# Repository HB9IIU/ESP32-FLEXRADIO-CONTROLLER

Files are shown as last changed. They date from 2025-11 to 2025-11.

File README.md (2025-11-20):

# FlexControl WiFi – ESP32 SmartSDR Tuning Knob

**FlexControl WiFi** is an ESP32-based network controller for **FlexRadio SmartSDR**.  
It talks to the SmartSDR CAT server over TCP (port 5002) and gives you a **hardware tuning knob** with:

- Main VFO encoder (with acceleration)
- Filter preset encoder (0–7)
- Volume encoder with mute
- Touch buttons for frequency presets, PTT and TUNE
- Mode cycling (USB / LSB )
- Status LEDs for CAT link and TX
- Captive-portal Wi-Fi configuration + OTA firmware updates

👉 All code and 3D enclosure files are **free and open source**.

## Demo Video

<p align="center">
  <a href="https://www.youtube.com/watch?v=9js4Cu4pR5Q" target="_blank">
    FlexControl WiFi Demo
  </a>
</p>

## Features

- 🌀 **Main tuning encoder**  
  - High-resolution quadrature decoder in ISR  
  - Frequency acceleration based on tuning speed  
  - Periodic `FA;` polling to keep in sync with SmartSDR

- 🎚 **Filter encoder**  
  - 8 filter presets: CAT command `ZZFI00`…`ZZFI07`  
  - Encoder steps mapped to filter index 0–7

- 🔊 **Volume encoder + mute**  
  - Volume 0–100% via `ZZAGnnn;`  
  - Mute / unmute on volume encoder click (remembers last volume)  
  - Auto-unmute if you turn the volume knob while muted

- 🧲 **Touch buttons (TTP223 modules)**  
  - Touch 1: FT8 @ **40 m** preset (7.077 MHz, LSB)  
  - Touch 2: FT8 @ **20 m** preset (14.074 MHz, USB)  
  - Touch 3: **PTT** (press & hold = TX, release = RX)  
  - Touch 4: **TUNE** (short carrier, low power, configurable)  
  - Touch 5: **Mode cycle** (USB ↔ LSB, extendable)

- 🧠 **Smart CAT handling**  
  - Auto-discovery of the SmartSDR CAT server on LAN  
  - Caching of last known CAT host in NVS (`Preferences`)  
  - Transparent handling of modes (MDn;), power (ZZPC), PTT (ZZTX)

- 🌐 **Wi-Fi captive portal + OTA**  
  - First-boot captive portal to capture Wi-Fi credentials  
  - Web console logger (serial-over-web)  
  - OTA updates via ArduinoOTA helper

- 🔁 **Factory reset**  
  - Press and hold factory reset button at boot to clear Wi-Fi / NVS  
  - Red LED indicates reset activity

---

## Hardware

- **ESP32 board** (classic ESP32 DevKit-style with GPIOs 32/33 etc.)
- Main VFO: high-resolution E38 optical encoder (600 PPR, NPN, powered at 5 V, A/B pulled up to 3.3 V on the ESP32).
- Filter & volume: two HW-040 mechanical encoders with integrated push switches (volume switch also used for mute / factory reset).
- 5× **TTP223 touch sensors** 
- 2× LEDs (GREEN, RED) for status and TX indication
- 1× **factory-reset / volume encoder** push button
- 3D-printed enclosure (STL/STEP files in this repo)

> 🛠 All 3D files for the enclosure are included in the repository.  
> Check the `doc/` folder for STEP/STL files.

---

## Wiring

Below is the wiring as used in the firmware (`main.cpp`).

### LEDs

| Function | ESP32 GPIO | Notes |
| --- | --- | ---|
| GREEN status LED  | **13** | CAT connected / mute indication |
| RED status / TX | **4** | TX, errors, blinking, reset LED |

> Both the “red LED” and the “reset LED” share GPIO 4 in the code.

### Rotary Encoders

All encoder A/B signals are read with internal pull-ups (`INPUT_PULLUP`).  
Encoder common pins go to **GND**.

#### Main VFO Encoder (frequency)

| Signal | ESP32 GPIO | Notes |
| --- | --- | --- |
| Encoder A  | **32** | Quadrature A |
| Encoder B  | **33** | Quadrature B |
| Push (BW)  | **16** | Active-LOW, internal pull-up |

#### Filter / BW Encoder

| Signal | ESP32 GPIO | Notes |
| --- | --- | ---|
| Encoder A | **26** | Quadrature A |
| Encoder B | **25** | Quadrature B |
| Push (BW) | **16** | Active-LOW, used to reboot the ESP32 (BW button) |

#### Volume Encoder

| Signal | ESP32 GPIO | Notes |
| --- | --- | --- |
| Encoder A  | **14** | Quadrature A |
| Encoder B  | **27** | Quadrature B |
| Push | **17** | Active-LOW, internal pull-up (also used for **factory reset** at boot) |

> Long-press on boot = factory reset (via `HB9IIUPortal::checkFactoryReset()`),  
> short press in normal operation = **mute / unmute**.

### Touch Buttons (TTP223)

TTP223 modules are wired as:

- `OUT` → corresponding GPIO (below)  
- `VCC` → 3.3 V  
- `GND` → GND

The firmware uses `INPUT_PULLDOWN`, with **touch = HIGH**, **idle = LOW**.

| Touch # | ESP32 GPIO | Function in firmware |
| --- | --- | --- |
| 1 | **23** | FT8 40 m preset (7.077 MHz, LSB) |
| 2 | **22** | FT8 20 m preset (14.074 MHz, USB)  |
| 3 | **21** | PTT (press = TX, release = RX) |
| 4 | **19** | TUNE (short carrier, low power) |
| 5 | **18** | Mode cycle (USB ↔ LSB) |

### Factory Reset

| Signal | ESP32 GPIO | Notes |
| --- | --- | --- |
| Factory reset button | **17** | Same physical button as volume push |
| Factory reset LED | **4** | Same red LED as TX / status |

At boot, `HB9IIUPortal::checkFactoryReset()` inspects this button to decide whether to erase NVS / Wi-Fi credentials.

---

## Firmware Overview

### Wi-Fi & Captive Portal

The project uses a custom helper:

- `HB9IIUPortal::begin()`  
  - Connects to stored Wi-Fi credentials if available  
  - Otherwise starts an **Access Point + captive portal** (`HB9IIUportalConfigurator.h`)  
  - Shows a status message in the web console

---
### 3D Renderings

<table>
  <tr>
    <td></td>
    <td></td>
    <td></td>
    <td></td>
  </tr>
  <tr>
    <td></td>
    <td></td>
    <td></td>
    <td></td>
  </tr>
</table>

---

### As-Built

<table>
  <tr>
    <td></td>
    <td></td>
    <td></td>
    <td></td>
  </tr>   

</table>

---
## Known Limitations & Notes

- **SmartSDR reconnect behaviour**  
  If you **power off the device while SmartSDR is running**, the controller can reconnect, but SmartSDR sometimes stops reacting to it until you **restart SmartSDR**.  
  If you instead do a **soft restart** of the controller by clicking the **BW (filter) encoder** (which reboots the ESP32), SmartSDR continues to work normally without needing a restart.

- **Touch sensor sensitivity**  
  The TTP223 touch sensors are very sensitive through the front panel. With the current enclosure wall thickness, they can sometimes trigger even when a finger is **2–3 mm away** from the plastic.  
  If I were to redesign the enclosure, I would **increase the thickness** in the touch sensor area (or reduce sensitivity) to make accidental triggers less likely.

## Final Notes

This is a hobby project built by an amateur coder and radio tinkerer – expect a few quirks and feel free to hack it to your needs.  
Have fun experimenting, modifying and improving the controller… and if you build your own version, I’d be happy to see it!

73 de HB9IIU

## License

This project is licensed under the **GNU General Public License v3.0 (GPL-3.0)**.

You are free to use, modify, and redistribute this software, including in commercial products, as long as any distributed derivative works are also licensed under GPL-3.0 and accompanied by their complete corresponding source code.

See the [LICENSE](./LICENSE) file for the full text.

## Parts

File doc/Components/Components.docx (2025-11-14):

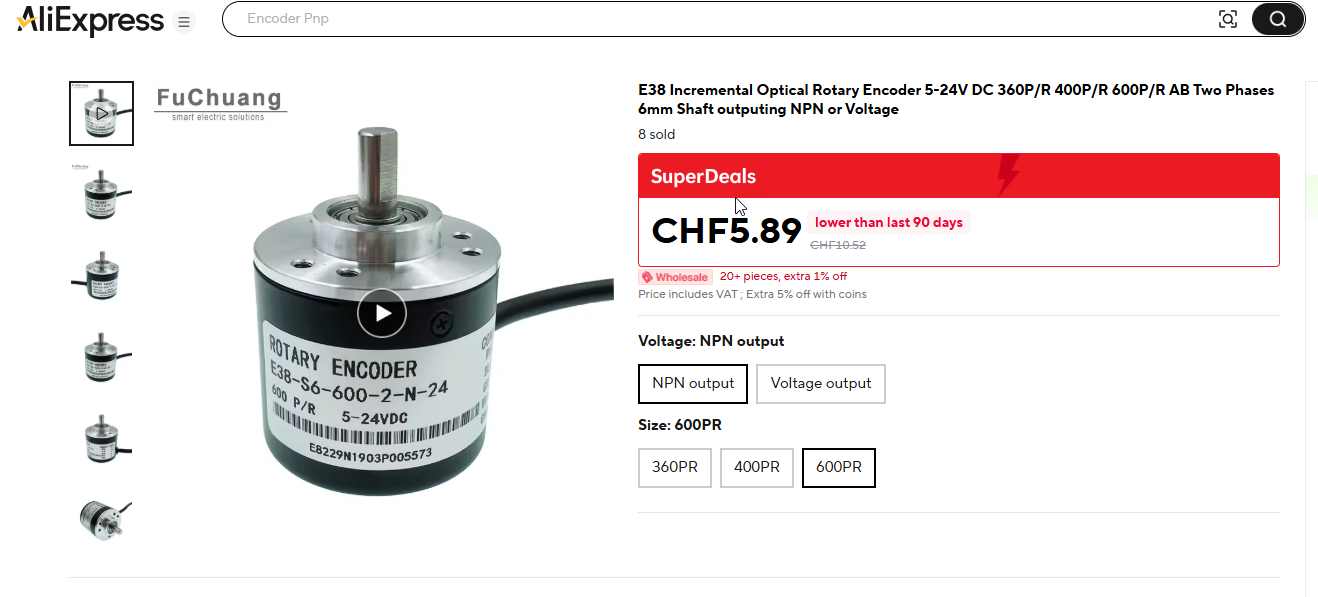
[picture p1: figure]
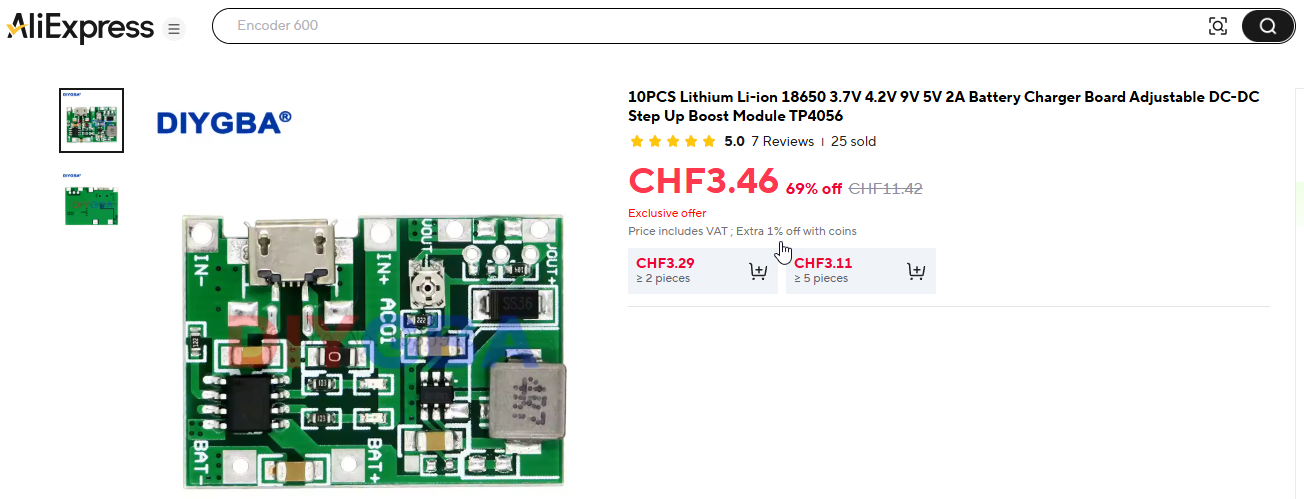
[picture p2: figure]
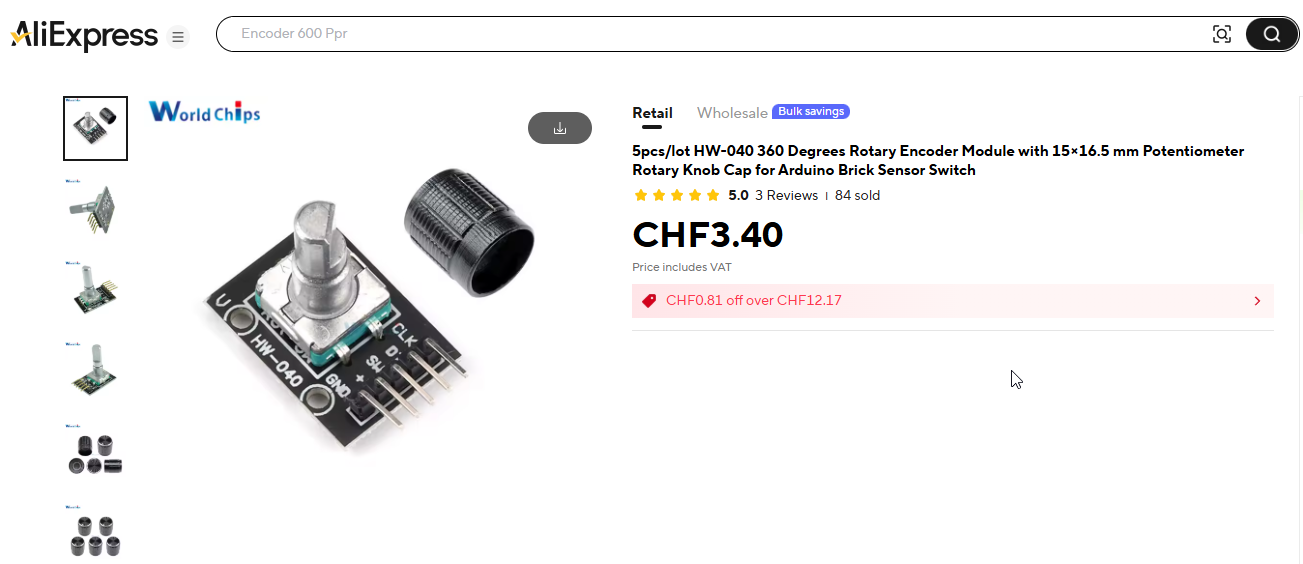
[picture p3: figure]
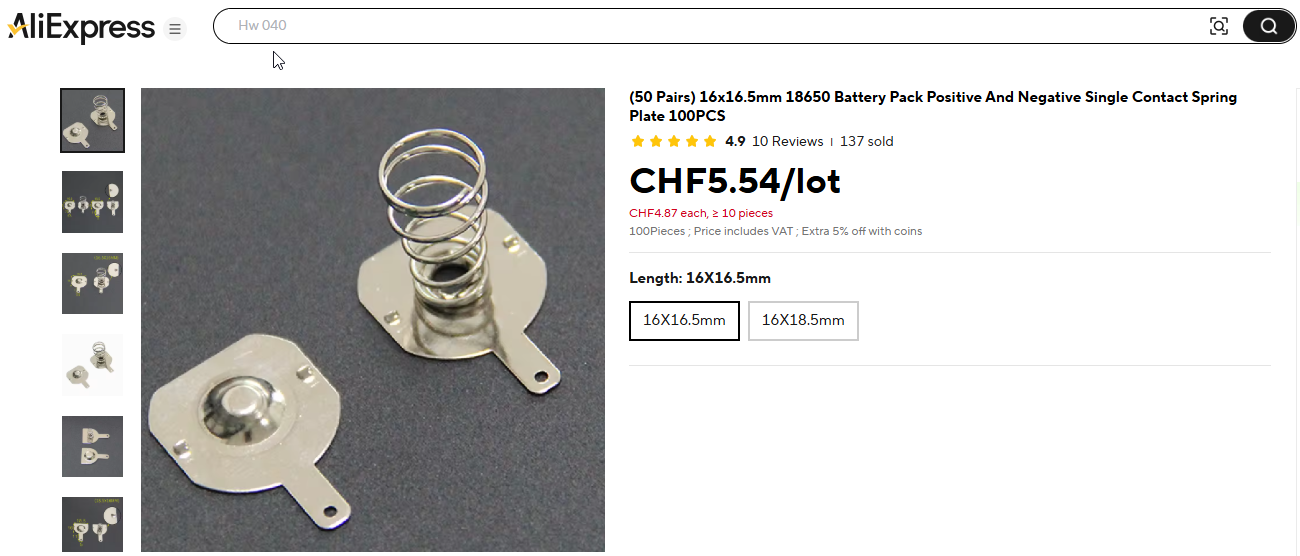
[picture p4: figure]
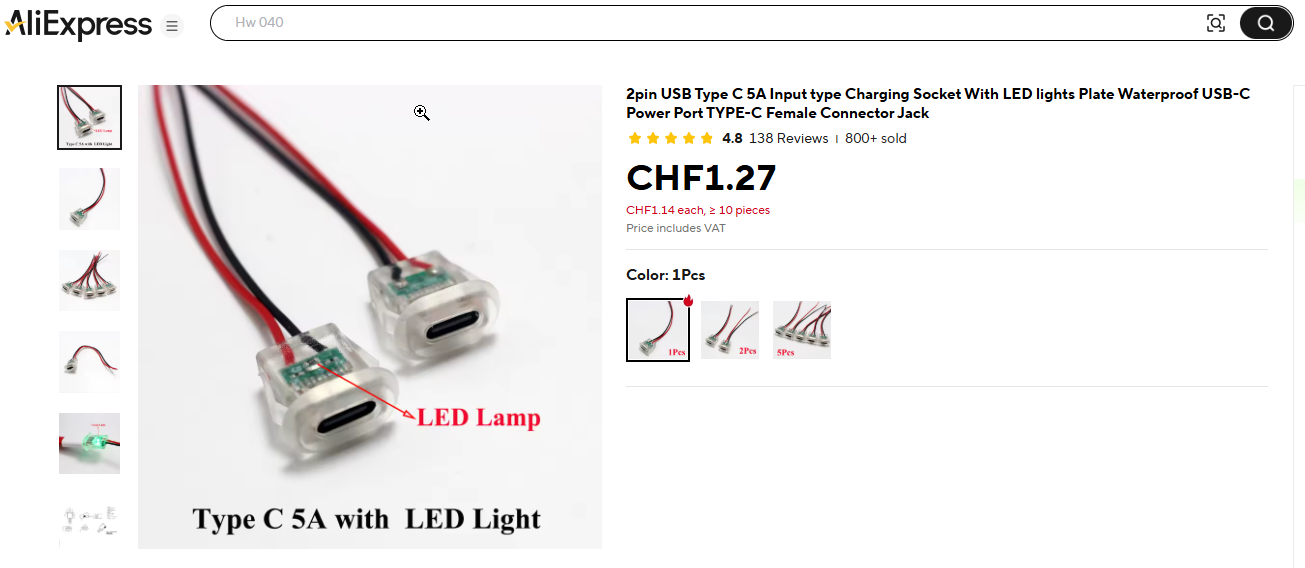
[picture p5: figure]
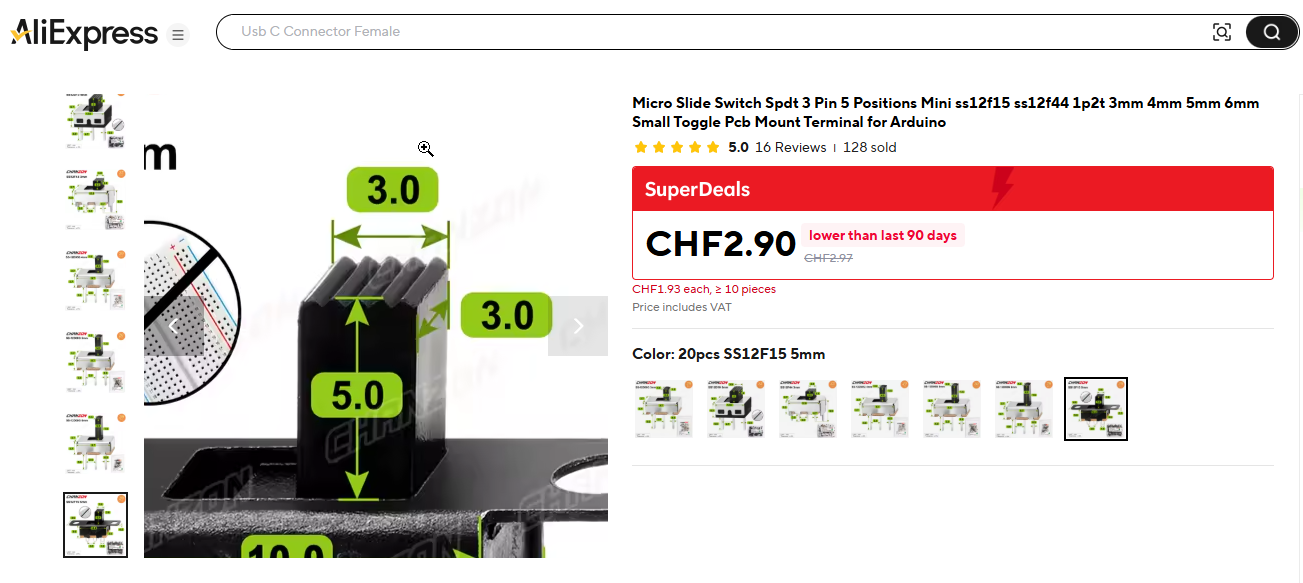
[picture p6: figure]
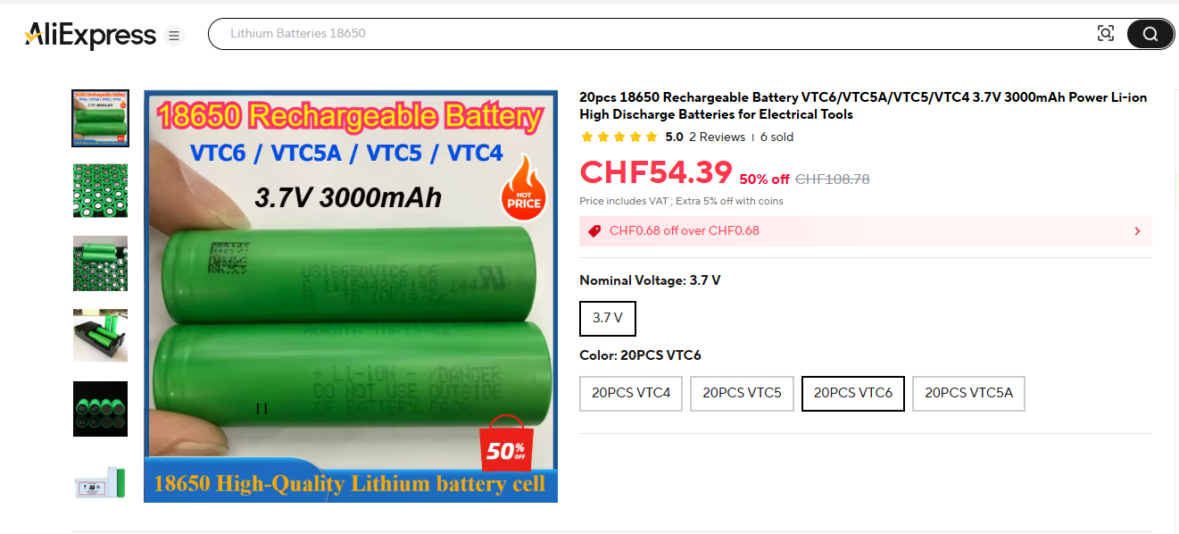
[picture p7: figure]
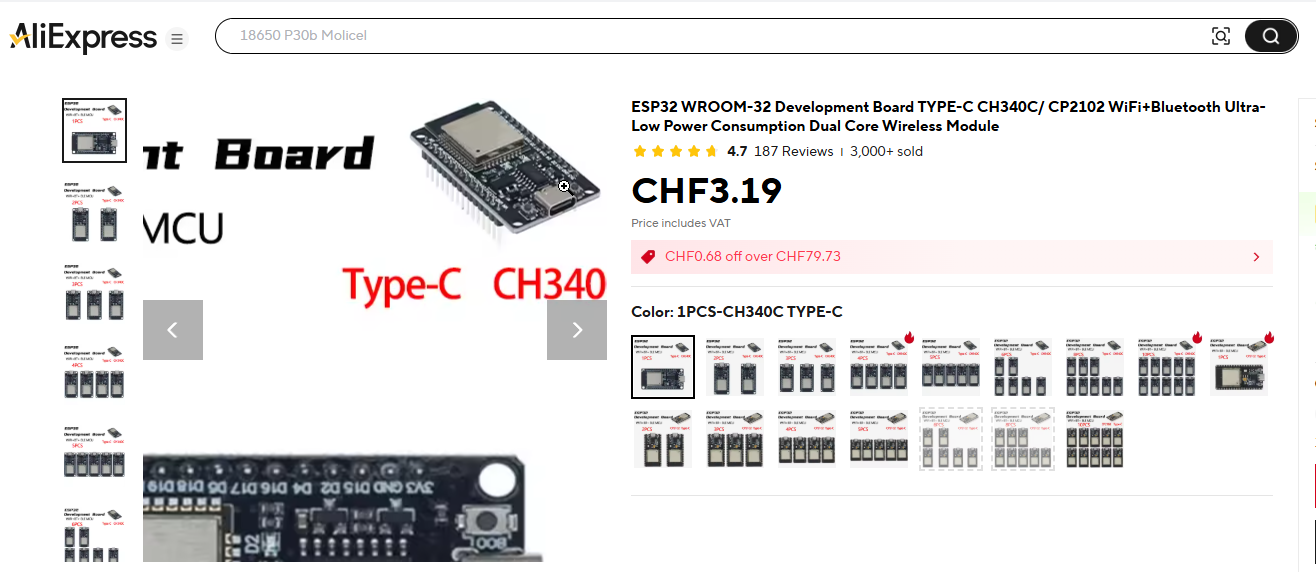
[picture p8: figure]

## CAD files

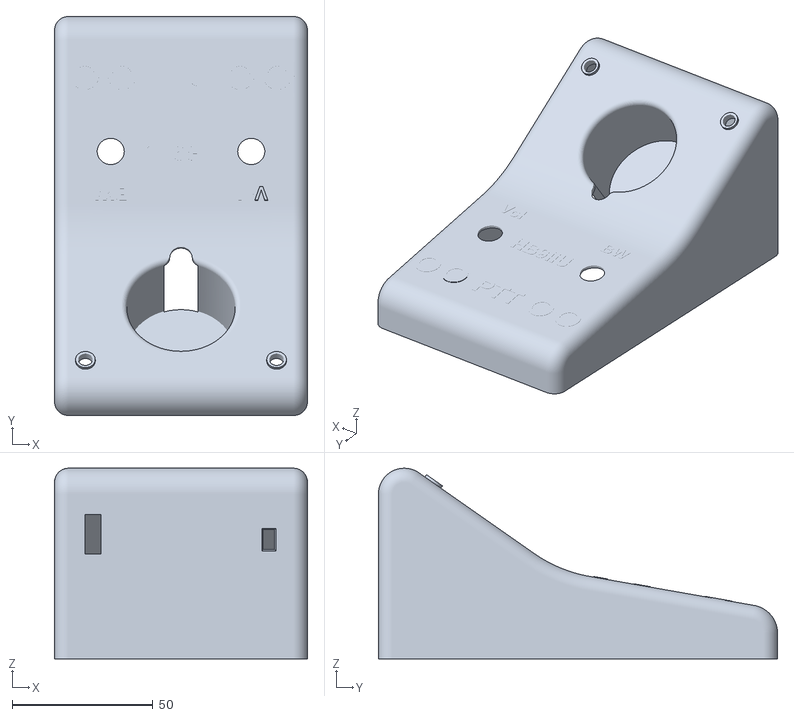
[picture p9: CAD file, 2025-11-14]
doc/STL files/TOP.stl
90.0 x 142.0 x 67.8

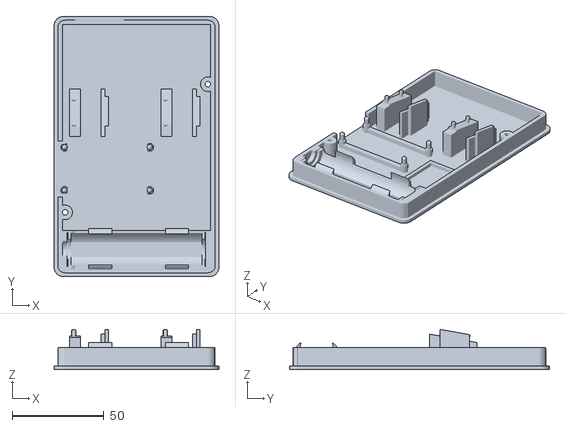
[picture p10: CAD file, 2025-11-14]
doc/STL files/BOTTOM.stl
90.0 x 142.0 x 21.9

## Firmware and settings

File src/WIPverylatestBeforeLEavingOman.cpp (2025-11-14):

/*
  ESP32 -> SmartSDR CAT (Kenwood FA) + Encoders + Preferences + Auto-Discover
  + 5x TTP223 Touch Inputs (active-HIGH, idle LOW) with simple debounce
  + 2x Encoder Click Buttons (active-LOW with INPUT_PULLUP) with simple debounce
/*
  TTP223 wiring:
  - VCC = 3.3V, GND = GND, OUT -> GPIO (18/19/21/22/23 here)
  - Pins are set to INPUT_PULLDOWN (idle LOW). Touch drives them HIGH.

  Encoder click buttons:
  - One side to GPIO (16 / 17), the other side to GND.
  - Pins use INPUT_PULLUP, so pressed = LOW.



  Touch1 = FT8 40m (7.074 MHz)
  Touch2 = FT8 20m (14.074 MHz)
  Freq Encoder Click = FT8 40m
  Vol  Encoder Click = FT8 20m
  Serial: 115200



*/

#include <WiFi.h>
#include <Preferences.h>

// ===== YOUR SETTINGS =====
const char *WIFI_SSID = "NO WIFI FOR YOU!!!";
const char *WIFI_PASS = "Nestle2010Nestle";
const IPAddress CAT_HOST(192, 168, 0, 5); // fallback if no cache / cache fails
const uint16_t CAT_PORT = 5002;
// =========================

// --- discovery timeouts (fast) ---
const uint32_t TCP_CONNECT_TIMEOUT_MS = 150;
const uint32_t SCAN_START_DELAY_MS = 800;
const uint8_t SCAN_BREATHER_MS = 6;

// --- LEDS ---
const int PIN_LED_GREEN = 13;
const int PIN_LED_RED = 4;

// ---- MAIN ENCODER (frequency) ----
const int PIN_ENC_A = 32;
const int PIN_ENC_B = 33;

// ---- FILTER ENCODER (preset 0..7) ----
const int PIN_FILT_A = 26;
const int PIN_FILT_B = 25;

// ---- VOLUME ENCODER ----
const int PIN_VOL_A = 14;
const int PIN_VOL_B = 27;

// ---- ENCODER CLICK BUTTONS (active-LOW with internal pull-ups) ----
const int PIN_ENC_BW_SW = 16;  // click of main (frequency) encoder
const int PIN_ENC_VOL_SW = 17; // click of volume encoder

// ---- VOLUME STEP (percent per detent) ----
const int VOLUME_STEP = 5; // change to 2/5/10 as you like

#define ENC_INPUT_MODE INPUT_PULLUP

// Frequency step/behavior
const int32_t STEP_HZ = 1;
const uint32_t SEND_INTERVAL_MS = 60;
const uint32_t RESYNC_MS = 800;
const uint32_t ACCEL_T1_MS = 35;
const uint32_t ACCEL_T2_MS = 80;

// ---- FT8 frequencies (Hz) ----
const uint32_t FT8_40M_HZ = 7077000UL;  // 7.074 MHz normally but i wat to hear LSB (just to see if teher is activity)
const uint32_t FT8_20M_HZ = 14074000UL; // 14.074 MHz

// ---- TTP223 TOUCH PINS (active-HIGH, idle LOW) ----
const int PIN_TOUCH1 = 23;
const int PIN_TOUCH2 = 22;
const int PIN_TOUCH3 = 21;
const int PIN_TOUCH4 = 19;
const int PIN_TOUCH5 = 18;

// Simple debounce
const uint16_t TOUCH_DEBOUNCE_MS = 50;
bool touchLast1 = false, touchLast2 = false, touchLast3 = false, touchLast4 = false, touchLast5 = false;
uint32_t touchT1 = 0, touchT2 = 0, touchT3 = 0, touchT4 = 0, touchT5 = 0;

// Encoder click debounce (active-LOW)
const uint16_t CLICK_DEBOUNCE_MS = 50;
bool clickLastBW = false, clickLastVol = false; // "pressed" state (LOW) after inversion
uint32_t clickTBW = 0, clickTVol = 0;

WiFiClient cat;
Preferences prefs;
IPAddress currentHost = CAT_HOST;

uint32_t vfoHz = 14110000, lastSentHz = vfoHz;

// ---------- Quadrature decoder (ISR) : MAIN ----------
static const int8_t QDEC_TAB[16] = {
    0, -1, +1, 0, +1, 0, 0, -1, -1, 0, 0, +1, 0, +1, -1, 0};

volatile uint8_t q_last = 0;
volatile int32_t q_edges = 0;
volatile uint32_t lastDetentMs = 0;
volatile int32_t detentPending = 0;
volatile bool needResetEncoderBaseline = false;

inline uint8_t fastReadAB()
{
  return (uint8_t(digitalRead(PIN_ENC_A)) << 1) | uint8_t(digitalRead(PIN_ENC_B));
}

void IRAM_ATTR encISR()
{
  uint8_t now = fastReadAB();
  uint8_t idx = (q_last << 2) | now;
  int8_t d = QDEC_TAB[idx];
  if (d)
  {
    q_edges += d;
    detentPending += d;
    if (detentPending >= 4 || detentPending <= -4)
    {
      lastDetentMs = millis();
      detentPending = 0;
    }
  }
  q_last = now;
}

// ---------- FILTER ENCODER ----------
volatile uint8_t f_q_last = 0;
volatile int32_t f_edges = 0;
int8_t filterIdx = 0; // 0..7

inline uint8_t fastReadAB_filt()
{
  return (uint8_t(digitalRead(PIN_FILT_A)) << 1) | uint8_t(digitalRead(PIN_FILT_B));
}

void IRAM_ATTR filtISR()
{
  uint8_t now = fastReadAB_filt();
  uint8_t idx = (f_q_last << 2) | now;
  int8_t d = QDEC_TAB[idx];
  if (d)
    f_edges += d;
  f_q_last = now;
}
// ---- LED helpers ----
inline void ledsOff()
{
  digitalWrite(PIN_LED_GREEN, LOW);
  digitalWrite(PIN_LED_RED, LOW);
}
inline void ledGreenSolid()
{
  digitalWrite(PIN_LED_GREEN, HIGH);
  digitalWrite(PIN_LED_RED, LOW);
}
inline void ledRedSolid()
{
  digitalWrite(PIN_LED_GREEN, LOW);
  digitalWrite(PIN_LED_RED, HIGH);
}

// Blink RED/GREEN alternately for durationMs (used instead of blocking delays)
void blinkAlt(uint32_t durationMs, uint16_t periodMs = 150)
{
  uint32_t t0 = millis();
  bool phase = false;
  while (millis() - t0 < durationMs)
  {
    // phase=false -> RED on, GREEN off; phase=true -> GREEN on, RED off
    digitalWrite(PIN_LED_RED, phase ? LOW : HIGH);
    digitalWrite(PIN_LED_GREEN, phase ? HIGH : LOW);
    phase = !phase;
    delay(periodMs); // replaces the old blocking delay(...)
  }
  ledsOff(); // stop blinking after the timed window
}

// --- non-blocking GREEN flash state ---
bool redFlashActive = false;
uint32_t redFlashUntil = 0;

// Call this to flash RED for ms (default ~120 ms)
inline void flashRedLed(uint16_t ms = 120)
{
  redFlashActive = true;
  redFlashUntil = millis() + ms;
  digitalWrite(PIN_LED_RED, HIGH); // start flash
}

// ---------- VOLUME ENCODER ----------
volatile uint8_t v_q_last = 0;
volatile int32_t v_edges = 0;
int16_t volumePct = 50; // 0..100

inline uint8_t fastReadAB_vol()
{
  return (uint8_t(digitalRead(PIN_VOL_A)) << 1) | uint8_t(digitalRead(PIN_VOL_B));
}

void IRAM_ATTR volISR()
{
  uint8_t now = fastReadAB_vol();
  uint8_t idx = (v_q_last << 2) | now;
  int8_t d = QDEC_TAB[idx];
  if (d)
    v_edges += d;
  v_q_last = now;
}

// ---------- Discovery helpers ----------
static bool tryConnectQuick(IPAddress host)
{
  WiFiClient probe;
  bool ok = probe.connect(host, CAT_PORT, TCP_CONNECT_TIMEOUT_MS);
  probe.stop();
  return ok;
}

static bool scanFirstOpen(IPAddress &found)
{
  IPAddress me = WiFi.localIP();
  IPAddress net(me[0], me[1], me[2], 0);
  delay(SCAN_START_DELAY_MS);
  for (int last = 1; last <= 254; last++)
  {
    if (last == (int)me[3])
      continue;
    IPAddress ip(net[0], net[1], net[2], last);
    if (tryConnectQuick(ip))
    {
      found = ip;
      return true;
    }
    delay(SCAN_BREATHER_MS);
  }
  return false;
}

// ---------- Wi-Fi / CAT ----------
bool wifiConnect()
{
  WiFi.mode(WIFI_STA);
  WiFi.begin(WIFI_SSID, WIFI_PASS);
  Serial.println("[WiFi] Connecting...");

  // start: green off, blink red
  digitalWrite(PIN_LED_GREEN, LOW);
  bool redState = false;
  uint32_t t0 = millis();
  uint32_t lastBlink = 0;

  while (WiFi.status() != WL_CONNECTED && millis() - t0 < 20000)
  {
    if (millis() - lastBlink >= 200)
    { // blink every 200 ms
      lastBlink = millis();
      redState = !redState;
      digitalWrite(PIN_LED_RED, redState);
    }
    delay(10);
  }

  // stop blinking
  digitalWrite(PIN_LED_RED, LOW);

  if (WiFi.status() == WL_CONNECTED)
  {
    Serial.print("[WiFi] IP: ");
    Serial.println(WiFi.localIP());
    return true;
  }
  else
  {
    Serial.println("[WiFi] FAILED");
    digitalWrite(PIN_LED_RED, HIGH); // solid red = failed (will reboot)
    return false;
  }
}

bool tryConnectHost(const IPAddress &host)
{
  if (cat.connected())
    cat.stop();
  delay(120);

  const uint16_t backoff[] = {600, 1200, 2000, 3500};

  for (uint8_t i = 0; i < 4; i++)
  {
    // show a quick alternating blink to indicate an active attempt
    digitalWrite(PIN_LED_RED, HIGH);
    digitalWrite(PIN_LED_GREEN, LOW);
    delay(120);
    digitalWrite(PIN_LED_RED, LOW);
    digitalWrite(PIN_LED_GREEN, HIGH);
    delay(120);
    ledsOff();

    Serial.printf("[CAT] Connecting %s:%u (try %u/4)\n",
                  host.toString().c_str(), CAT_PORT, i + 1);

    if (cat.connect(host, CAT_PORT, TCP_CONNECT_TIMEOUT_MS))
    {
      cat.setNoDelay(true);
      cat.setTimeout(1200);
      Serial.println("[CAT] Connected.");
      ledGreenSolid(); // ✅ solid green when CAT is up
      return true;
    }

    // connection failed -> alternate-blink during backoff window
    blinkAlt(backoff[i]); // ⏳ replaces delay(backoff[i])
  }

  // all tries failed
  ledRedSolid(); // ❌ solid red (you reboot after this anyway)
  return false;
}

bool catConnect()
{
  String cached = prefs.getString("host", "");
  if (cached.length())
  {
    IPAddress ip;
    if (ip.fromString(cached))
    {
      Serial.printf("[CACHE] Trying cached host: %s\n", cached.c_str());
      if (tryConnectHost(ip))
      {
        currentHost = ip;
        return true;
      }
      Serial.println("[CACHE] Cached host failed.");
    }
  }
  Serial.printf("[CAT] Trying default host: %s\n", CAT_HOST.toString().c_str());
  if (tryConnectHost(CAT_HOST))
  {
    currentHost = CAT_HOST;
    return true;
  }

  Serial.println("[SCAN] Scanning subnet for CAT (TCP 5002) ...");
  IPAddress found;
  if (scanFirstOpen(found))
  {
    Serial.printf("[SCAN] Found CAT at %s\n", found.toString().c_str());
    if (tryConnectHost(found))
    {
      currentHost = found;
      return true;
    }
  }
  Serial.println("[SCAN] No CAT found.");
  return false;
}

void saveCurrentHostIfNeeded()
{
  String cached = prefs.getString("host", "");
  String nowStr = currentHost.toString();
  if (cached != nowStr)
  {
    prefs.putString("host", nowStr);
    Serial.printf("[SAVE] Stored CAT host: %s\n", nowStr.c_str());
  }
}

bool readLine(String &out, uint32_t waitMs)
{
  uint32_t t0 = millis();
  while (millis() - t0 < waitMs)
  {
    if (cat.available())
    {
      String s = cat.readStringUntil(';');
      if (s.length())
      {
        out = s + ';';
        return true;
      }
    }
    delay(2);
    yield();
  }
  return false;
}

bool sendFA(uint32_t hz)
{
  if (!cat.connected())
    return false;
  char digits[16];
  snprintf(digits, sizeof(digits), "%011u", hz);
  char cmd[24];
  snprintf(cmd, sizeof(cmd), "FA%s;", digits);
  Serial.print(">> ");
  Serial.println(cmd);
  return cat.print(cmd) == (int)strlen(cmd);
}

// ----- Filter preset (ZZFI) -----
bool sendFilterPreset(uint8_t idx)
{
  if (!cat.connected())
    return false;
  if (idx > 7)
    idx = 7;
  char cmd[16];
  snprintf(cmd, sizeof(cmd), "ZZFI%02u;", idx);
  Serial.print(">> ");
  Serial.println(cmd);
  return cat.print(cmd) == (int)strlen(cmd);
}

void readFilterPresetOnce()
{
  if (!cat.connected())
    return;
  cat.print("ZZFI;");
  String line;
  if (readLine(line, 800) && line.startsWith("ZZFI") && line.endsWith(";") && line.length() >= 6)
  {
    filterIdx = line.substring(4, line.length() - 1).toInt();
    if (filterIdx < 0)
      filterIdx = 0;
    if (filterIdx > 7)
      filterIdx = 7;
    Serial.printf("[FILTER] Current preset = %d\n", filterIdx);
  }
  else
  {
    Serial.println("[FILTER] No reply; defaulting to 0");
    filterIdx = 0;
  }
}

// ----- Volume (Flex ZZAGnnn; 000..100) -----
bool setVolumeA(uint8_t lvl)
{
  if (!cat.connected())
    return false;
  if (lvl > 100)
    lvl = 100;
  char cmd[16];
  snprintf(cmd, sizeof(cmd), "ZZAG%03u;", lvl);
  Serial.print(">> ");
  Serial.println(cmd);
  return cat.print(cmd) == (int)strlen(cmd);
}

int readVolumeA()
{ // 0..100 or -1
  if (!cat.connected())
    return -1;
  cat.print("ZZAG;");
  String line;
  if (!readLine(line, 800))
    return -1; // expect "ZZAGnnn;"
  if (!line.startsWith("ZZAG") || !line.endsWith(";"))
    return -1;
  return line.substring(4, line.length() - 1).toInt();
}

// ----- Sync VFO from radio -----
bool initialSyncFromRadio()
{
  if (!cat.connected())
    return false;
  cat.print("FA;");
  String line;
  if (!readLine(line, 1500))
    return false;
  if (!line.startsWith("FA") || line.length() < 14)
    return false;
  String d = line.substring(2, 13);
  vfoHz = (uint32_t)d.toInt();
  lastSentHz = vfoHz;
  noInterrupts();
  q_edges = 0;
  detentPending = 0;
  q_last = fastReadAB();
  interrupts();
  Serial.printf("[SYNC] Start at %.6f MHz\n", vfoHz / 1e6);
  return true;
}

// ----- Incoming CAT pump -----
void pumpIncoming()
{
  while (cat.connected() && cat.available())
  {
    String s = cat.readStringUntil(';');
    if (!s.length())
      break;
    s += ';';
    if (s == "?;")
    {
      Serial.println("<< ?; (ignored)");
    }
    else if (s.startsWith("FA") && s.length() >= 14)
    {
      String d = s.substring(2, 13);
      uint32_t rxHz = (uint32_t)d.toInt();
      Serial.print("<< ");
      Serial.println(s);
      if (rxHz != vfoHz)
      {
        vfoHz = rxHz;
        lastSentHz = rxHz;
        needResetEncoderBaseline = true;
        Serial.printf("[EXT] Radio → %.6f MHz (sync)\n", vfoHz / 1e6);
      }
    }
    else
    {
      Serial.print("<< ");
      Serial.println(s);
    }
  }
}

// ====== SIMPLE ACTIONS ======
void setFrequencyHz(uint32_t hz)
{
  vfoHz = hz;
  if (cat.connected())
  {
    if (sendFA(vfoHz))
      lastSentHz = vfoHz;
    else
    {
      Serial.println("[CAT] Send failed; stopping socket.");
      cat.stop();
    }
  }
  needResetEncoderBaseline = true;
  Serial.printf("[ACTION] VFO set to %.6f MHz\n", vfoHz / 1e6);
}

// --- implementation (place with your CAT helpers)
static int mdCodeFromString(String m)
{
  m.toUpperCase();
  if (m == "LSB")
    return 1;
  if (m == "USB")
    return 2;
  if (m == "CW")
    return 3;
  if (m == "FM")
    return 4; // NFM/DFM/FDV family
  if (m == "AM" || m == "SAM")
    return 5;
  if (m == "DIGL" || m == "RTTY")
    return 6;
  if (m == "DIGU")
    return 9;
  return -1;
}

bool setMode(const String &mode)
{
  if (!cat.connected())
    return false;
  int code = mdCodeFromString(mode);
  if (code < 0)
  {
    Serial.printf("[MD] Unknown mode '%s'\n", mode.c_str());
    return false;
  }
  char cmd[12];
  snprintf(cmd, sizeof(cmd), "MD%d;", code);
  Serial.print(">> ");
  Serial.println(cmd);
  return cat.print(cmd) == (int)strlen(cmd);
}

int getMode()
{ // reads current mode (MDn) -> n
  if (!cat.connected())
    return -1;
  cat.print("MD;");
  String line;
  if (!readLine(line, 800))
    return -1; // expect "MDn;"
  if (!line.startsWith("MD") || !line.endsWith(";"))
    return -1;
  return line.substring(2, line.length() - 1).toInt();
}

bool setPTT(bool on)
{
  if (!cat.connected())
    return false;
  const char *cmd = on ? "ZZTX1;" : "ZZTX0;";
  Serial.print(">> ");
  Serial.println(cmd);
  return cat.print(cmd) == (int)strlen(cmd);
}

// Cleanly close CAT + Wi-Fi before rebooting (very small + safe)
inline void cleanCloseNet() {
  if (cat.connected()) {
    cat.stop();         // closes TCP with FIN
    delay(50);
  }
  WiFi.disconnect(true, true);  // drop STA and forget current link
  delay(100);
}



// --- prototypes
void setFT8_40m() { setFrequencyHz(FT8_40M_HZ); }
void setFT8_20m() { setFrequencyHz(FT8_20M_HZ); }
void rebootESP();
bool setPTT(bool on);
bool setMode(const String &mode);
int getMode();                 // returns MD code or -1 on fail
bool setPowerPct(uint8_t pct); // ZZPC 000..100
int getPowerPct();             // 0..100 or -1
bool setModeCode(int code);    // send MDn; directly

void startTune(uint16_t ms = 1200, uint8_t tunePower = 10, const String &tuneMode = "AM");
void serviceTune(); // call from loop()

// --- RF Power via ZZPC (SmartSDR CAT)
bool setPowerPct(uint8_t pct)
{
  if (!cat.connected())
    return false;
  if (pct > 100)
    pct = 100;
  char cmd[12];
  snprintf(cmd, sizeof(cmd), "ZZPC%03u;", pct);
  Serial.print(">> ");
  Serial.println(cmd);
  return cat.print(cmd) == (int)strlen(cmd);
}

int getPowerPct()
{ // returns 0..100 or -1 on fail
  if (!cat.connected())
    return -1;
  cat.print("ZZPC;");
  String line;
  if (!readLine(line, 800))
    return -1; // expect "ZZPCnnn;"
  if (!line.startsWith("ZZPC") || !line.endsWith(";"))
    return -1;
  return line.substring(4, line.length() - 1).toInt();
}
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
void loop()
{
  if (cat.connected() && cat.available())
    pumpIncoming();

  // reconnect if needed
  static uint32_t lastTry = 0;
  if (!cat.connected() && millis() - lastTry > 1200)
  {
    lastTry = millis();
    if (!tryConnectHost(currentHost))
    {
      if (!catConnect())
      {
        Serial.println("[CAT] Reconnect failed; rebooting...");
        delay(500);
        ESP.restart();
      }
    }
    saveCurrentHostIfNeeded();
    if (!initialSyncFromRadio())
    {
      sendFA(vfoHz);
      lastSentHz = vfoHz;
    }
    readFilterPresetOnce();
    int v = readVolumeA();
    if (v >= 0)
      volumePct = v;
  }

  // External change sync baseline
  static int32_t lastEdges = 0;
  if (needResetEncoderBaseline)
  {
    noInterrupts();
    q_edges = 0;
    detentPending = 0;
    interrupts();
    needResetEncoderBaseline = false;
    noInterrupts();
    lastEdges = q_edges;
    interrupts();
  }

  // MAIN ENCODER: freq detents + accel
  int32_t edges;
  noInterrupts();
  edges = q_edges;
  interrupts();
  int32_t deltaEdges = edges - lastEdges;
  int32_t detents = deltaEdges / 4;
  if (detents != 0)
  {
    lastEdges += detents * 4;
    uint32_t nowMs = millis();
    uint32_t dt = nowMs - lastDetentMs;
    int accel = 1;
    if (dt < ACCEL_T1_MS)
      accel = 4;
    else if (dt < ACCEL_T2_MS)
      accel = 2;
    long next = (long)vfoHz + (long)detents * STEP_HZ * accel;
    if (next < 0)
      next = 0;
    vfoHz = (uint32_t)next;
  }

  // Rate-limited FA
  static uint32_t lastSend = 0;
  if (cat.connected() && millis() - lastSend >= SEND_INTERVAL_MS)
  {
    lastSend = millis();
    if (vfoHz != lastSentHz)
    {
      if (sendFA(vfoHz))
        lastSentHz = vfoHz;
      else if (cat.connected())
        cat.stop();
    }
  }

  // Light periodic FA;
  static uint32_t lastFAq = 0;
  if (RESYNC_MS > 0 && cat.connected() && millis() - lastFAq > RESYNC_MS)
  {
    lastFAq = millis();
    cat.print("FA;");
  }

  // FILTER ENCODER: 4 edges = 1 detent; step 0..7
  static int32_t f_lastEdges = 0;
  int32_t fe;
  noInterrupts();
  fe = f_edges;
  interrupts();
  int32_t f_delta = fe - f_lastEdges;
  int32_t f_detents = f_delta / 4;
  if (f_detents != 0)
  {
    f_lastEdges += f_detents * 4;
    int8_t dir = (f_detents > 0) ? +1 : -1;
    int8_t newIdx = filterIdx + dir;
    if (newIdx < 0)
      newIdx = 0;
    if (newIdx > 7)
      newIdx = 7;
    if (newIdx != filterIdx)
    {
      filterIdx = newIdx;
      sendFilterPreset((uint8_t)filterIdx);
    }
  }

  // VOLUME ENCODER: each detent = VOLUME_STEP %, clamp 0..100, throttle sends
  static int32_t v_lastEdges = 0;
  static uint32_t lastVolSend = 0;
  static int16_t lastVolSent = -1;

  int32_t ve;
  noInterrupts();
  ve = v_edges;
  interrupts();
  int32_t v_delta = ve - v_lastEdges;
  int32_t v_detents = v_delta / 4;
  if (v_detents != 0)
  {
    v_lastEdges += v_detents * 4;
    int16_t newVol = volumePct + (int16_t)v_detents * VOLUME_STEP;
    if (newVol < 0)
      newVol = 0;
    if (newVol > 100)
      newVol = 100;
    volumePct = newVol;
  }
  if (cat.connected() && volumePct != lastVolSent && millis() - lastVolSend >= 120)
  {
    if (setVolumeA((uint8_t)volumePct))
    {
      lastVolSent = volumePct;
      lastVolSend = millis();
    }
  }

  // ===== SIMPLE TOUCH HANDLING (active-HIGH, debounced) =====
  uint32_t t = millis();

  bool r1 = digitalRead(PIN_TOUCH1);
  if (r1 != touchLast1 && (t - touchT1) >= TOUCH_DEBOUNCE_MS)
  {
    touchLast1 = r1;
    touchT1 = t;
    if (r1)
    {
      Serial.println("[TTP] 1 -> FT8 40m; mode: LSB");
      flashRedLed();
      setFT8_40m();
      setMode("LSB");
    }
  }
  bool r2 = digitalRead(PIN_TOUCH2);
  if (r2 != touchLast2 && (t - touchT2) >= TOUCH_DEBOUNCE_MS)
  {
    touchLast2 = r2;
    touchT2 = t;
    if (r2)
    {
      Serial.println("[TTP] 2 -> FT8 20m; mode: USB");
      flashRedLed();
      setFT8_20m();
      setMode("USB");
    }
  }
  bool r3 = digitalRead(PIN_TOUCH3);
  if (r3 != touchLast3 && (t - touchT3) >= TOUCH_DEBOUNCE_MS)
  {
    touchLast3 = r3;
    touchT3 = t;
    if (r3)
    { // finger down
      Serial.println("[TTP] 3 -> PTT ON");
      setPTT(true);
      digitalWrite(PIN_LED_RED, HIGH);
    }
    else
    { // finger up
      Serial.println("[TTP] 3 -> PTT OFF");
      setPTT(false);
      digitalWrite(PIN_LED_RED, LOW);
    }
  }
  bool r4 = digitalRead(PIN_TOUCH4);
  if (r4 != touchLast4 && (t - touchT4) >= TOUCH_DEBOUNCE_MS)
  {
    touchLast4 = r4;
    touchT4 = t;
    if (r4)
    {
      Serial.println("[TTP] 4 pressed -> TUNE");
      flashRedLed();
      startTune(/*ms*/ 1200, /*power%*/ 10, /*mode*/ "FM");
    }
  }
  bool r5 = digitalRead(PIN_TOUCH5);
  if (r5 != touchLast5 && (t - touchT5) >= TOUCH_DEBOUNCE_MS)
  {
    touchLast5 = r5;
    touchT5 = t;
    if (r5)
    {
      Serial.println("[TTP] 5 pressed (no action)");
      flashRedLed();
    }
  }

  // ===== ENCODER CLICK HANDLING (active-LOW, debounced) =====
  bool cfRaw = !digitalRead(PIN_ENC_BW_SW); // pressed if LOW
  if (cfRaw != clickLastBW && (t - clickTBW) >= CLICK_DEBOUNCE_MS)
  {
    clickLastBW = cfRaw;
    clickTBW = t;
    if (cfRaw)
    {
      Serial.println("[CLICK] BW");
      rebootESP();
    }
  }

  bool cvRaw = !digitalRead(PIN_ENC_VOL_SW); // pressed if LOW
  if (cvRaw != clickLastVol && (t - clickTVol) >= CLICK_DEBOUNCE_MS)
  {
    clickLastVol = cvRaw;
    clickTVol = t;
    if (cvRaw)
    {
      Serial.println("[CLICK] Vol -> FT8 20m");
      setFT8_20m();
    }
  }
  if (redFlashActive && (int32_t)(millis() - redFlashUntil) >= 0)
  {
    redFlashActive = false;
    digitalWrite(PIN_LED_RED, LOW); // end flash
  }

  serviceTune();

  delay(1);
}

void rebootESP()
{
cleanCloseNet();
  // fast blink RED 5 times (about 0.8s total)
  for (int i = 0; i < 5; ++i) {
    digitalWrite(PIN_LED_GREEN, LOW);
    digitalWrite(PIN_LED_RED, HIGH);
    delay(80);
    digitalWrite(PIN_LED_RED, LOW);
    delay(80);
  }
  ESP.restart();
}

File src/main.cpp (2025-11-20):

/*
 * FlexControl WiFi – ESP32 SmartSDR Tuning Knob
 *
 * Author: Daniel (HB9IIU)
 * First release: November 2025
 *
 * I'm an amateur coder, so forgive the mess :)
 *
 * Contact: hb9iiu@gmail.com
 * (Replies can be very slow – I still have a day job and this is just a hobby.)
 *
 * You are free to use, modify and redistribute this code,
 * but please do NOT sell it. If you improve it, a mention
 * or pull request on GitHub would be very welcome.
 *
 * GitHub: https://github.com/HB9IIU/ESP32-FLEXRADIO-CONTROLLER
 */


#include <Arduino.h>
#include "HB9IIUWebConsoleLogger.h"
#include <HB9IIUportalConfigurator.h>
#include "HB9IIUOtaHelper.h"
#include <WiFi.h>
#include <WebServer.h>
#include <Preferences.h>

// --- LEDS ---
const int PIN_LED_GREEN = 13;
const int PIN_LED_RED = 4;

// ---- VFO ENCODER (frequency) ----
const int PIN_ENC_A = 32;
const int PIN_ENC_B = 33;

// ---- FILTER ENCODER (preset 0..7) ----
const int PIN_FILT_A = 26;
const int PIN_FILT_B = 25;

// ---- VOLUME ENCODER ----
const int PIN_VOL_A = 14;
const int PIN_VOL_B = 27;

// ---- ENCODER CLICK BUTTONS (active-LOW with internal pull-ups) ----
const int PIN_ENC_BW_SW = 16;  // click of main (frequency) encoder
const int PIN_ENC_VOL_SW = 17; // click of volume encoder

// ---- HOLD DOWN FACTORY RESET -----
const int PIN_LED_RED_RESET = 4;
const int PIN_FACTORY_RESET_SW = 17;

const char *OTA_HOSTNAME = "flexcontroller"; // should match with platformio.ini

// When true, send debug output to the web terminal as well as Serial.
// Disable (set to false) if the app starts behaving unreliably.
bool webDebug = true;
String debugMessage;

const uint16_t CAT_PORT = 5002;

// --- discovery timeouts (fast) ---
const uint32_t TCP_CONNECT_TIMEOUT_MS = 150;
WebServer server(80);

// ===== LED BLINK TASK STUFF =====
TaskHandle_t ledBlinkTaskHandle = nullptr;
volatile bool ledBlinkActive = false;

// ---- FT8 frequencies (Hz) ----
const uint32_t FT8_40M_HZ = 7077000UL;  // 7.074 MHz normally but i wat to hear LSB (just to see if teher is activity)
const uint32_t FT8_20M_HZ = 14074000UL; // 14.074 MHz

// --- prototypes ----------------------------------------------------

// Blink task
void ledBlinkTask(void *parameter);
// Read CAT-line
bool readLine(String &out, uint32_t waitMs);
// Send VFO
bool sendFA(uint32_t hz);
// Send filter
bool sendFilterPreset(uint8_t idx);
// Read filter
void readFilterPresetOnce();
// Set volume
bool setVolumeA(uint8_t lvl);
// Read volume
int readVolumeA();
// Sync VFO
bool initialSyncFromRadio();
// Pump CAT
void pumpIncoming();
// Connect host
bool tryConnectHost(const IPAddress &host);
// Connect CAT
bool catConnect();
// Save CAT-host
void saveCurrentHostIfNeeded();
// Close network
void cleanCloseNet();
// Set frequency
void setFrequencyHz(uint32_t hz);
// FT8 40m
inline void setFT8_40m() { setFrequencyHz(FT8_40M_HZ); }
// FT8 20m
inline void setFT8_20m() { setFrequencyHz(FT8_20M_HZ); }
// Set mode
bool setMode(const String &mode);
// Get mode
int getMode(); // returns MD code or -1 on fail
// Set mode-code
bool setModeCode(int code); // send MDn; directly
// Set PTT
bool setPTT(bool on);
// Set RF-power
bool setPowerPct(uint8_t pct); // ZZPC 000..100
// Get RF-power
int getPowerPct(); // 0..100 or -1
// Cycle modes
void cycleModeSequence(); // USB -> LSB -> CW -> FM -> ...
// Start tune
void startTune(uint16_t ms = 1200, uint8_t tunePower = 10, const String &tuneMode = "AM");
// Service tune
void serviceTune();
// Startup banner
void printStartupHeader();
// Mute toggle
void muteUnmute();
// Update GREEN
void updateGreenLed();
// Reboot ESP
void rebootESP();

//---------------------------------------------------------------------------------------------------------------------

void ledBlinkTask(void *parameter)
{
  pinMode(PIN_LED_RED_RESET, OUTPUT);
  bool state = false;

  for (;;)
  {
    if (ledBlinkActive)
    {
      digitalWrite(PIN_LED_RED_RESET, state ? HIGH : LOW);
      state = !state;
      vTaskDelay(pdMS_TO_TICKS(200)); // blink every 200 ms
    }
    else
    {
      // make sure LED is off when not active
      digitalWrite(PIN_LED_RED_RESET, LOW);
      vTaskDelay(pdMS_TO_TICKS(50));
    }
  }
}

//-------------------------------------------------------------------

// ---- VOLUME STEP (percent per detent) ----
const int VOLUME_STEP = 5; // change to 2/5/10 as you like

#define ENC_INPUT_MODE INPUT_PULLUP

// Frequency step/behavior
const int32_t STEP_HZ = 1;
const uint32_t SEND_INTERVAL_MS = 60;
const uint32_t RESYNC_MS = 800;
const uint32_t ACCEL_T1_MS = 35;
const uint32_t ACCEL_T2_MS = 80;

// ---- TTP223 TOUCH PINS (active-HIGH, idle LOW) ----
const int PIN_TOUCH1 = 23;
const int PIN_TOUCH2 = 22;
const int PIN_TOUCH3 = 21;
const int PIN_TOUCH4 = 19;
const int PIN_TOUCH5 = 18;

// Simple debounce
const uint16_t TOUCH_DEBOUNCE_MS = 100;
bool touchLast1 = false, touchLast2 = false, touchLast3 = false, touchLast4 = false, touchLast5 = false;
uint32_t touchT1 = 0, touchT2 = 0, touchT3 = 0, touchT4 = 0, touchT5 = 0;

// Encoder click debounce (active-LOW)
const uint16_t CLICK_DEBOUNCE_MS = 50;
bool clickLastBW = false, clickLastVol = false; // "pressed" state (LOW) after inversion
uint32_t clickTBW = 0, clickTVol = 0;

WiFiClient cat;
Preferences prefs;
IPAddress currentHost;

uint32_t vfoHz = 14110000, lastSentHz = vfoHz;

// ---------- Quadrature decoder (ISR) : MAIN ----------
static const int8_t QDEC_TAB[16] = {
    0, -1, +1, 0, +1, 0, 0, -1, -1, 0, 0, +1, 0, +1, -1, 0};
volatile uint8_t vfo_q_last = 0;
volatile int32_t q_edges = 0;
volatile uint32_t lastDetentMs = 0;
volatile int32_t detentPending = 0;
volatile bool needResetEncoderBaseline = false;

inline uint8_t fastReadAB()
{
  return (uint8_t(digitalRead(PIN_ENC_A)) << 1) | uint8_t(digitalRead(PIN_ENC_B));
}

void IRAM_ATTR encISR()
{
  uint8_t now = fastReadAB();
  uint8_t idx = (vfo_q_last << 2) | now;
  int8_t d = QDEC_TAB[idx];
  if (d)
  {
    q_edges += d;
    detentPending += d;
    if (detentPending >= 4 || detentPending <= -4)
    {
      lastDetentMs = millis();
      detentPending = 0;
    }
  }
  vfo_q_last = now;
}

// ---------- FILTER ENCODER ----------
volatile uint8_t f_q_last = 0;
volatile int32_t f_edges = 0;
int8_t filterIdx = 0; // 0..7

inline uint8_t fastReadAB_filt()
{
  return (uint8_t(digitalRead(PIN_FILT_A)) << 1) | uint8_t(digitalRead(PIN_FILT_B));
}

void IRAM_ATTR filtISR()
{
  uint8_t now = fastReadAB_filt();
  uint8_t idx = (f_q_last << 2) | now;
  int8_t d = QDEC_TAB[idx];
  if (d)
    f_edges += d;
  f_q_last = now;
}
// ---- LED helpers ----
inline void ledsOff()
{
  digitalWrite(PIN_LED_GREEN, LOW);
  digitalWrite(PIN_LED_RED, LOW);
}
inline void ledGreenSolid()
{
  digitalWrite(PIN_LED_GREEN, HIGH);
  digitalWrite(PIN_LED_RED, LOW);
}
inline void ledRedSolid()
{
  digitalWrite(PIN_LED_GREEN, LOW);
  digitalWrite(PIN_LED_RED, HIGH);
}
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
